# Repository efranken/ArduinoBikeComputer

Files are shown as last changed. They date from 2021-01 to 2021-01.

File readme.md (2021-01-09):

### Arduino Bike Computer


**List of items required**

1.  Arduino Nano
2.  Nextion NX3224T024
3.  3.5mm jack headset extension cable (cable muse have 3 black rings on
    pin end)
4.  USB battery (I used an Aukey 5000mAh)
5.  Jumper wires and speaker wire, or any other kind of similar wire
6.  Pulldown resistor for hall effect sensor
7.  Magnet for bike spoke
8.  Hall effect sensor

 **Wiring it all up**
  First things first - measure the distance from where
you want to mount the computer to where you'll place the sensor (likely
on the chainstay near the outside of the wheel) and keep this in mind as
you measure out the length for the sensor end of the wires.

 - Arduino wires
1.  VIN to Nextion power supply positive
2.  5V to split - 3.5mm jack socket end red wire and Nextion +
3.  GND to split - 3.5mm jack socket end white wire and Nextion -
4.  GND to Nextion power supply negative (2 wires in same GND on my
    build)
5.  TX to yellow Nextion
6.  RX to blue Nextion
7.  D2 to 3.5mm jack socket end yellow wire

- Sensor side of 3.5mm jack (pin end)

1.  Left most pin to split - 3.5mm jack pin end red wire (5V) and
    pulldown resistor
2.  Middle pin to 3.5mm jack pin end yellow wire
3.  Right most pin to split - 3.5mm jack pin end and white wire (GND)
    and pulldown resistor

\
 Bike Computer wiring progress 

**Loading the Arduino:** 

1.  Download the Nextion.H library, see "troubleshooting" below if using
    Arduino with only 1 serial
2.  Place library in necessary location
3.  Load the .tft file from the Nextion Screen file onto an SD card (NO
    OTHER FILES ON SD CARD)
4.  Power off Nextion, insert SD card, wait for load, power off, remove
    SD card
5.  Open the code from Arduino Code/ArduinoBikeComputer folder
6.  Compile the code and upload to Arduino

**Printing the case:** 
\
 Not much to say here - print the case out on a 3d printer or use a web
store to get it done. It takes a bit to cram all the wires in there, but
you can put some superglue or other around the edges to get it all to
stay together. The brackets on the bottom of the extruded cylinder are
used to tywrap the case to handlebars. 

Bike Computer Case 

### Troubleshooting

I used an Arduino Nano for this. The Nextion.h library is set up to use
an Arduino with multiple serial ports by default. First build of my code
I got this -

        In file included from C:\Program Files (x86)\Arduino\libraries\ITEADLIB_Arduino_Nextion-master\NexHardware.h:18:0,
            from C:\Program Files (x86)\Arduino\libraries\ITEADLIB_Arduino_Nextion-master\NexHardware.cpp:15:
        C:\Program Files (x86)\Arduino\libraries\ITEADLIB_Arduino_Nextion-master\NexHardware.cpp: In function 'bool recvRetNumber(uint32_t*, uint32_t)':
        C:\Program Files (x86)\Arduino\libraries\ITEADLIB_Arduino_Nextion-master\NexConfig.h:37:19: error: 'Serial2' was not declared in this scope
        #define nexSerial Serial2
                       ^
        C:\Program Files (x86)\Arduino\libraries\ITEADLIB_Arduino_Nextion-master\NexHardware.cpp:55:5: note: in expansion of macro 'nexSerial'
            nexSerial.setTimeout(timeout);
            ^~~~~~~~~

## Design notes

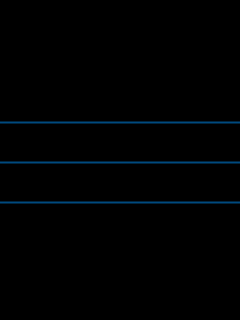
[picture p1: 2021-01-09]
Nextion Screen/Other/nextionBG.png

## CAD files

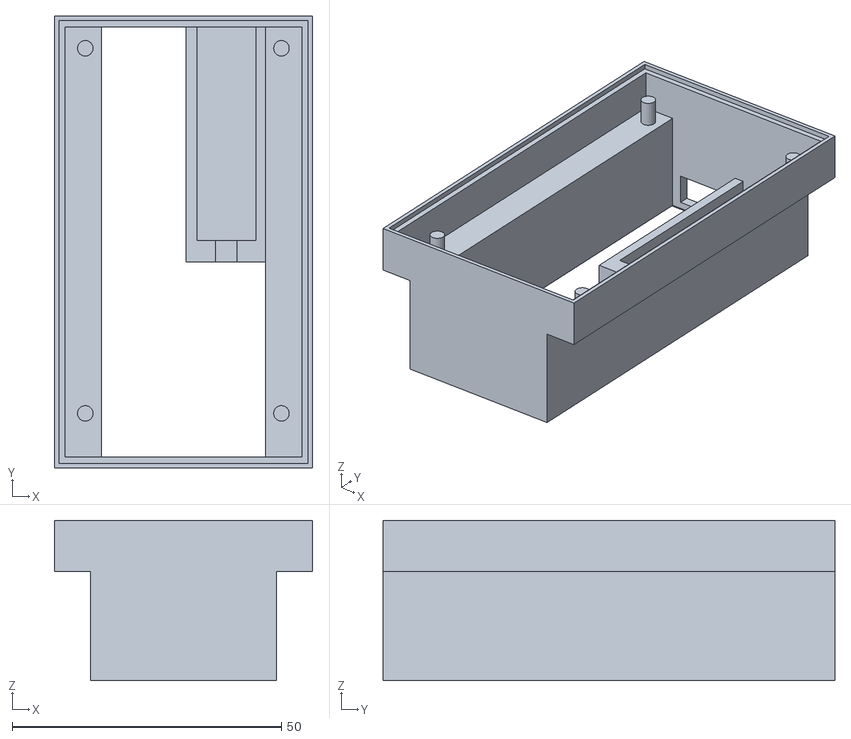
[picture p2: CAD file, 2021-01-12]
Case/middle.stl
48.0 x 84.0 x 29.7

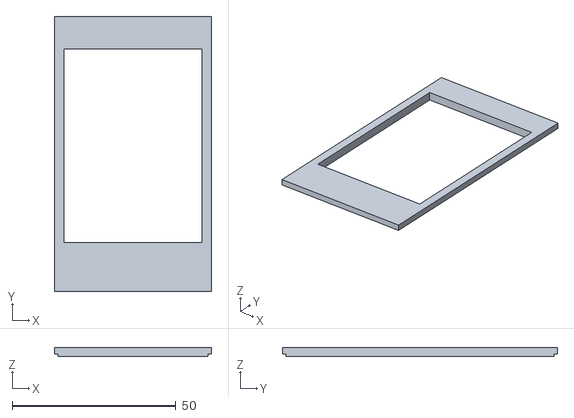
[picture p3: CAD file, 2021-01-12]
Case/top.stl
48.0 x 84.0 x 2.80

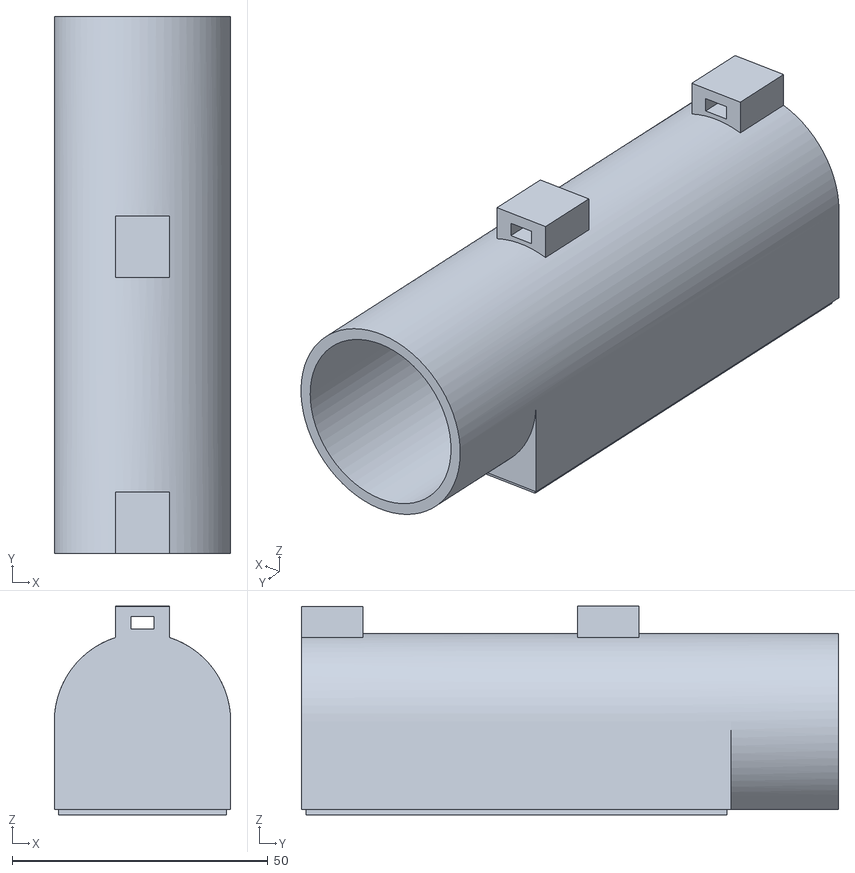
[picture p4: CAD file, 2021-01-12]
Case/bottom.stl
34.5 x 105.0 x 40.8

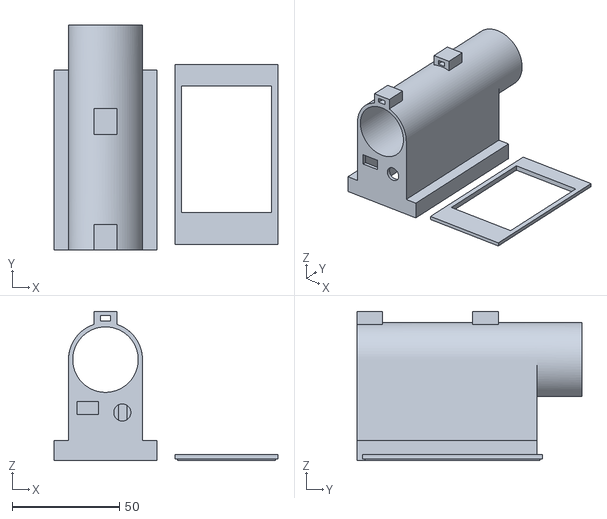
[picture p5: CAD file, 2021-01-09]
Case/bike case 2 piece.stl
104.4 x 105.0 x 69.7

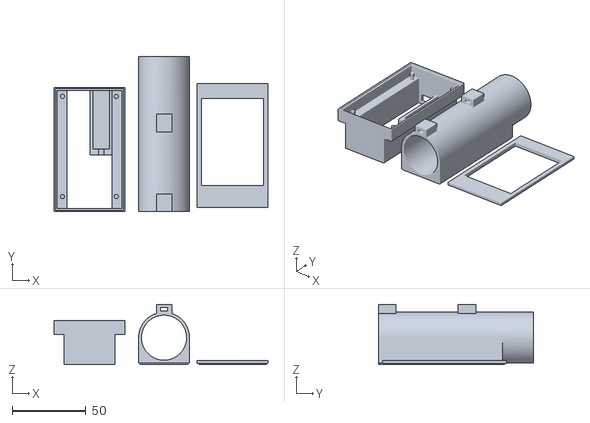
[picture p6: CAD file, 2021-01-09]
Case/bike case 3 piece.stl
144.9 x 105.0 x 40.8

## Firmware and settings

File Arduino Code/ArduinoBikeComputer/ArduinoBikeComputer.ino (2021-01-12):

#include "Nextion.h"

const byte ReedPin = 3; // pin connected to reed switch
const float WheelRadius = 0.00020728245;// the wheel radius in miles
const float WheelCircumference = 2 * PI * WheelRadius;
const float MPHconst = WheelCircumference * 3600000.0; // Killometers per hour at 1 revolution per millisecond.

float elapsedHr;

NexText avgmph = NexText(0, 4, "avgmph");
NexText timer = NexText(0, 5, "time");
NexText mph = NexText(0, 6, "mph");
NexText distance = NexText(0, 9, "distance");

const unsigned DebounceTime = 10;  // Milliseconds of bouncing to ignore

unsigned TickCounter = 0;
volatile float totalVelocity = 0;
volatile float avgMph = 0;
volatile int totalTick = 0;

// Shared with the ISR.  Must mark as 'volatile' so the compiler knows
// they can change at any time
volatile float CurrentVelocity = 0.00; // mph
volatile float TotalDistance = 0.00; // km

void setup()
{
  Serial.begin(9600);
  pinMode(ReedPin, INPUT);
  noInterrupts();

  TCCR1A = 0;// set entire TCCR1A register to 0
  TCCR1B = 0;// set entire TCCR1B register to 0
  TCNT1  = 0;// initialize counter value to 0
  TCCR1B |= (1 << WGM12);// set to Waveform Generation Mode 4 (CTC mode, TOP is in OCR1A)
  OCR1A = 1999;// set TOP for 1kHz interrupts  = (16*10^6) / (1000*8) - 1
  TCCR1B |= (1 << CS11);  // Set CS11 bit for 8 prescaler (2 MHz clock)
  TIMSK1 |= (1 << OCIE1A);  // enable timer compare interrupt

  interrupts();
}

void loop()
{
  displayText();

  delay(100);
}

// Interrupt occurs every millisecond
ISR(TIMER1_COMPA_vect)
{
  static unsigned long lastStateChangeTime = 0;
  static boolean reedWasClosed = false;

  unsigned long currentTime = millis();


  boolean reedIsClosed = digitalRead(ReedPin);

  // Check for state change
  if (reedIsClosed != reedWasClosed && currentTime - lastStateChangeTime > DebounceTime)
  {
    reedWasClosed = reedIsClosed;
    lastStateChangeTime = currentTime;
    if (reedIsClosed)
    {
      // Reed Has Just Closed
      TotalDistance += WheelCircumference;

      // KPHconst is KPH at 1 revolution per tick.
      CurrentVelocity = MPHconst / TickCounter;
      if (CurrentVelocity < 100)
      {
        totalVelocity += CurrentVelocity;
        totalTick += 1;
        avgMph = totalVelocity / totalTick;
      }

      TickCounter = 0;
    }
  }

  if (TickCounter > 4000)// Count milliseconds unless the wheel has stopped
  {
    CurrentVelocity = 0;// set velocity to 0 when tire is still for 4 seconds - 2 seconds had a low speed of 14.8mph
    //totalTick += 1;
  }
  else
  {
    TickCounter++;
  }
}


void displayText()
{
  // Because 'volatile' variables can change any time interrupts are enabled
  // we have to make local copies while interrupts are disables.  If we don't
  // the value of the variable might change half-way thourgh fetching!

  unsigned long allSeconds = millis() / 1000; //time calculation variables, these get placed here because if they are outside
  int secsRemaining = allSeconds % 3600;  //of a loop or looped function they will never update
  int runMinutes = secsRemaining / 60;
  int runSeconds = secsRemaining % 60;


  float localTotalDistance;
  float localTotalDistanceFT;
  float localTotalDistanceMI;
  float localCurrentVelocity;
  float localCurrentVelocityK;
  float localAvgMph;

  noInterrupts();
  localTotalDistance = TotalDistance;
  localCurrentVelocity = CurrentVelocity;
  localCurrentVelocityK = CurrentVelocity * 1.60934;
  localAvgMph = avgMph;
  interrupts();
  localTotalDistanceFT = (localTotalDistance * 5280);
  localTotalDistanceMI = localTotalDistance;


  //  Serial.print(int(localCurrentVelocity));
  //  Serial.println(" km/h");
  //


  //Distance

  char dist[21];
  if (((TotalDistance * 5280) / 12) > 5280) {
    Serial.print(localTotalDistance / 12);
    Serial.println(" M");
    dtostrf(localTotalDistanceMI, 4, 3, dist);
    nexSerial.write(0xFF);
    nexSerial.write(0xFF);
    nexSerial.write(0xFF);
    distance.setText(dist);
  }
  else {
    Serial.print(int(localTotalDistance * 1000.0));
    Serial.println(" FT");
    dtostrf(localTotalDistanceFT, 4, 1, dist);
    nexSerial.write(0xFF);
    nexSerial.write(0xFF);
    nexSerial.write(0xFF);
    distance.setText(dist);
  }




  //time elapsed
  char elapsed[21];
  sprintf(elapsed, "%02d:%02d", runMinutes, runSeconds);
  nexSerial.write(0xFF);
  nexSerial.write(0xFF);
  nexSerial.write(0xFF);
  timer.setText(elapsed);

  //avgmph
  char speedoAvg[4];
  dtostrf(localAvgMph, 4, 1, speedoAvg);
  Serial.println(localCurrentVelocity);
  nexSerial.write(0xFF);
  nexSerial.write(0xFF);
  nexSerial.write(0xFF);
  avgmph.setText(speedoAvg);


  //mph
  char speedoM[4];
  dtostrf(localCurrentVelocity, 4, 1, speedoM);
  Serial.println(localCurrentVelocity);
  nexSerial.write(0xFF);
  nexSerial.write(0xFF);
  nexSerial.write(0xFF);
  mph.setText(speedoM);

  //
  ////kph
  //  char speedoK[4];
  //  dtostrf(localCurrentVelocityK, 4, 1, speedoK);
  //  Serial.println(localCurrentVelocityK);
  //  nexSerial.write(0xFF);
  //  nexSerial.write(0xFF);
  //  nexSerial.write(0xFF);
  //  kph.setText(speedoK);
}

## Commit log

2020-10-06 Hall effect sensor detecting magnets and notes
    Going to try to figure out the logic for detecting time between events next
2020-10-09 Created SensorAndScreen
    removed some code from original to make it easier to read how to print text
    need to figure out how to keep it from pushing lines down, clear screen quickly, and print in place
    need to go to bed
2021-01-06 Avg, MPH, KPH, Timer working
2021-01-09 Final build
    Built and tested the final product. Removed all other files in order to package it up nicely.
    [bike case 2 piece.stl, bike case 3 piece.stl]
2021-01-12 fixed distance calculations
    fixed distance calc and added 3 piece case design
    [bottom.stl, middle.stl, top.stl]
